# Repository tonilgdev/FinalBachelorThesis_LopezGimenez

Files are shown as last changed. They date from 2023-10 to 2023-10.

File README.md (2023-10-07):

# Antoni López Giménez's final bachelor's degree thesis repository

SEPTEMBER '23 UPDATE
> Currently, the repository is public and contains all the documents, code and hardware. The aim is to make it easily accessible.

ABSTRACT
> The aim of this project is to carry out a study of variations in human peripheral temperature as affected by stress, sleep and/or physical activity. To do this we have divided the project into two parts: the development of the measurement system and the assessment of this end. In order to be able to carry out the assessment correctly, we need to develop a system that can obtain the peripheral temperature of the subject to be studied and also know if it has been affected by physical activity. For this purpose we have developed a measurement system with a temperature sensor and an accelerometer as well as an RTC to be able to know at what instant of time the data have been collected. Finally, the assessment consists of the test subject taking the system with him/her for 2-3 days and returning it to download the data for analysis.

© 2021 Antoni López Giménez. All rights reserved.

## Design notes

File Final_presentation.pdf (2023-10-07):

Author: Antoni López

Advisor: Juan José Ramos

# Design of a system for ambulatory measurement of peripheral temperature

# Abstract

- The aim of this project is:
- Variations in human peripheral temperature as affected by stress, sleep and/or physical activity.
- Development of the measurement system.
- Peripheral temperature of the subject to be studied and its relation with physical activity.
- Measurement system with a temperature sensor and an
accelerometer.
- 2-3 subject study.

## Index

1. Introduction
a. Statement of purpose
b. Requirements and specifications
c. Methods and procedures
2. State of the art
a. Why peripheral temperature?
b. Specific components and I2C bus
c. Software tools
3. Project development
a. Hardware part
b. Software part
4. Results
5. Budget
6. Conclusions
a. Project conclusions
b. Own conclusions
c. Incidents
7. Future Development

# Introduction

## Statement of purpose

- Previous scientific studies about peripheral temperature
- Develop the measurement system
- Specific hardware

## Requirements

- User-friendly
- Similar to Smartwatch
- 2-3 autonomy days with data storage
- Continuous recording of Temperature and physical activity

## Specifications (I)

- Microcontroller
- RTC (Real Time Clock)
- EEPROM memory
- micro-USB connection
- USB charger
- LDO (Low Dropout
Regulators)
- Temperature sensors (2)
- Accelerometer
- Battery
- Reset button
- In Circuit Programing
interface
- Optional: three LEDS
(Green, Blue and Red)

Specifications (II) ● Arduino IDE ● Short time execution ● Auto-sleep mode ● Test mode → Print Data ● Menu with sections: ○ | STOP ○ | START ○ | SEND ○ | RESET ○ | READ

## Methods and procedures

- Previous work in the lab
- Adafruit Trinket M0
- Own PCB
■ USB charger
■ LDO
■ EEPROM memory
■ Temperature sensors
- No physical activity measurement
- Union of the two parts
- Code and components changes

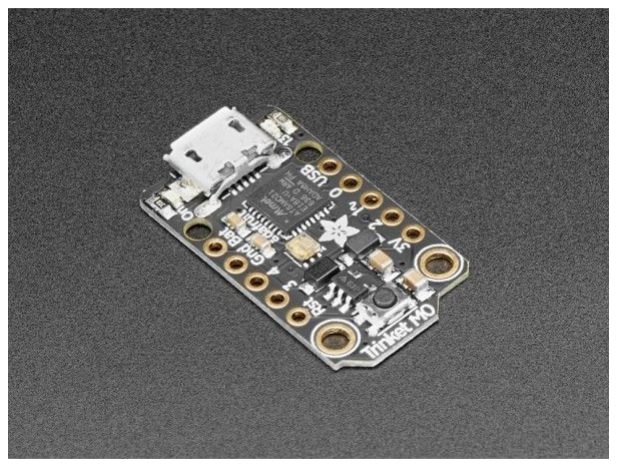
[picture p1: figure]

# State of the art

## Why peripheral temperature?

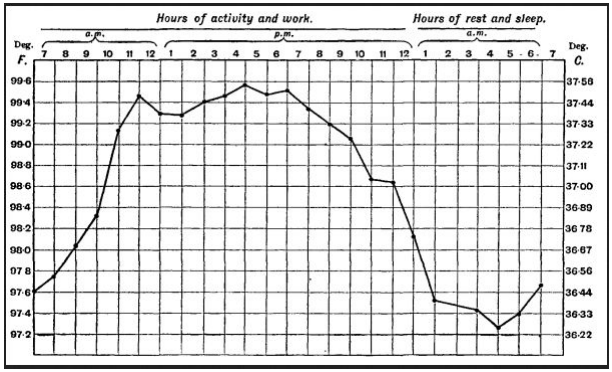
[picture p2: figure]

## Specific components and I2C bus

- Components compatible with I2C bus
- ¿Why I2C bus?
- ¿How works I2C bus?

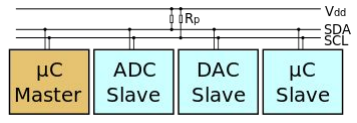
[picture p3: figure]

## Software tools

- KiCad EDA → PCB design
- Arduino IDE → Microcontroller programming
- Microchip Studio → Upload Arduino bootloader
- CoolTermWin → Terminal to store data
- Freedom Sensor Toolbox → Accelerometer Software
- Matlab → Convert Data
- Fusion 360 → Box design

# Project Development

## Hardware part (Block Diagram)

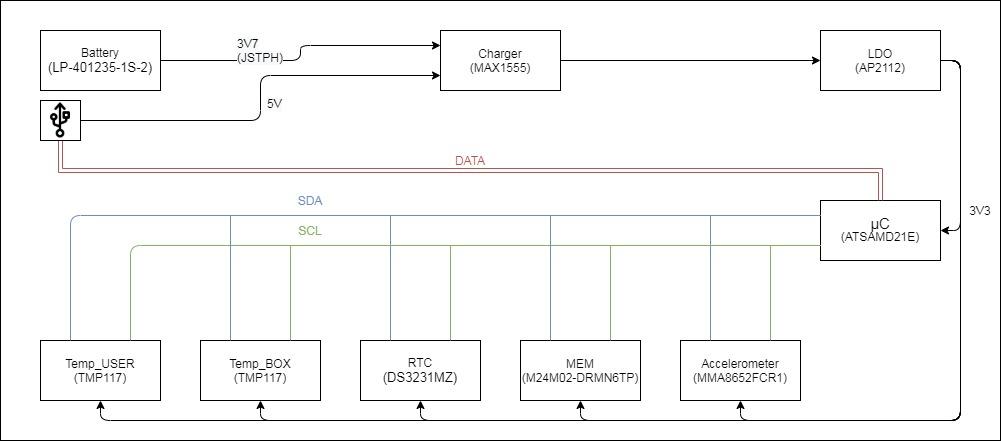
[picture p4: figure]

## Hardware part (Schematic)

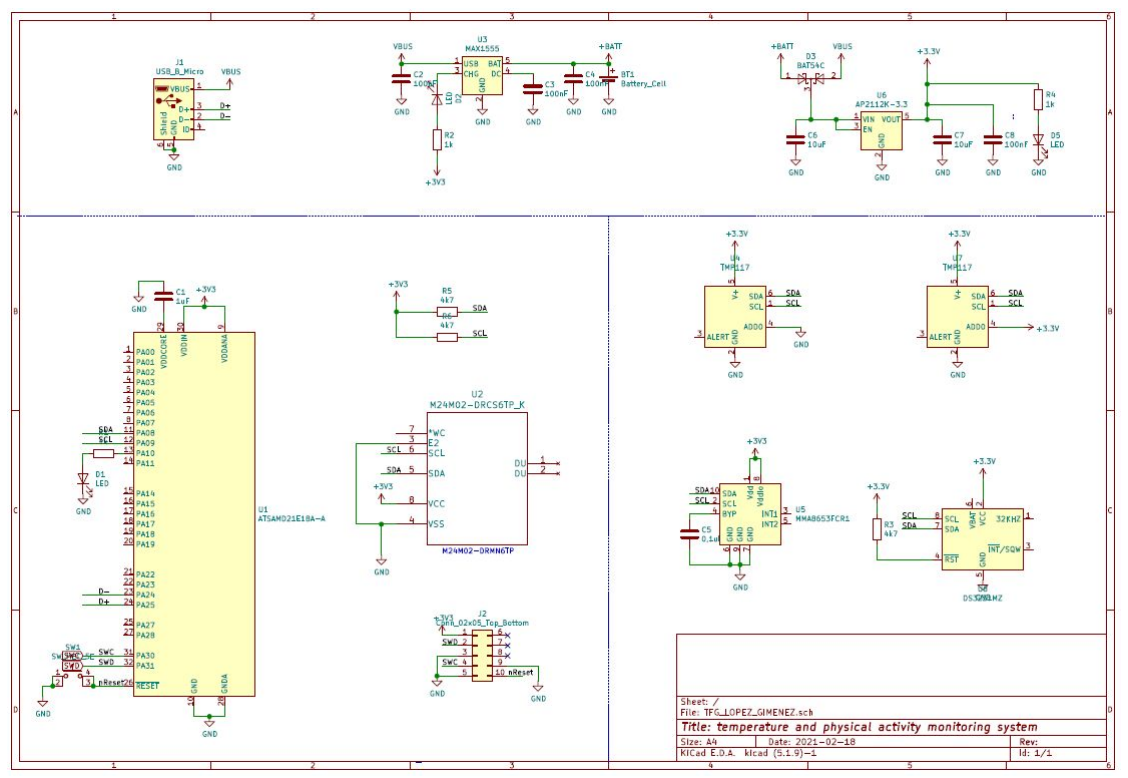
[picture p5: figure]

# Hardware Part

- Temperature:
- Accuracy: ±0.2°C (–10°C to +85°C)
- Resolution: 0.0078°C
- Sensor type: Diode temperature sensor?
- Physical activity → accelerometer:
- Type of sensor: capacitive micromachined accelerometer
- How it works? Integrated embedded functions + 3 capacitance transducers
- Saving information → EEPROM memory

## Hardware part (Prototype board)

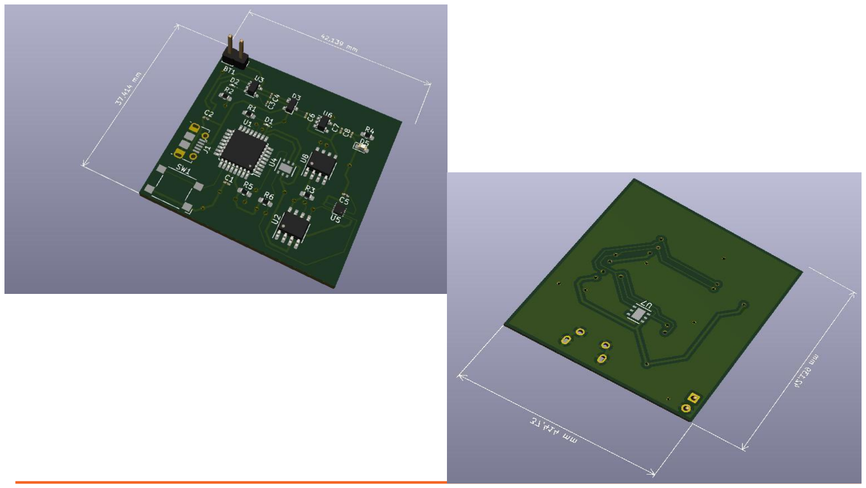
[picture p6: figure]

## Hardware part (Final board)

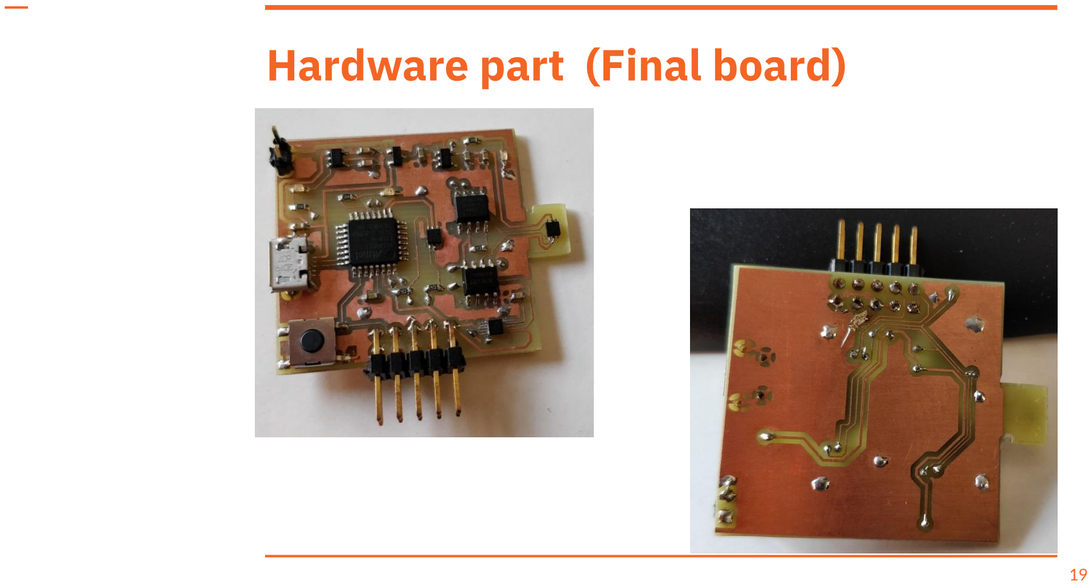
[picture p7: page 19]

## Software part

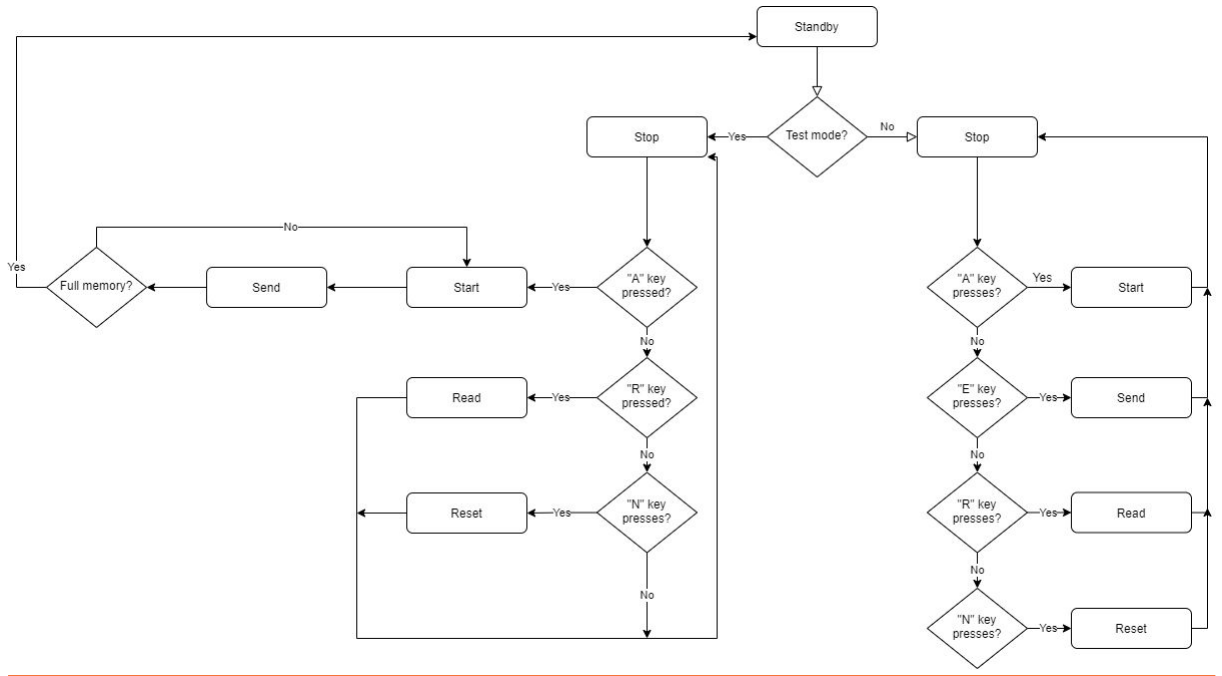
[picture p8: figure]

# Software Part

- Struct Data: ○ [Byte] day ○ [Byte] month ○ [Int] year ○ [Byte] hour ○ [Byte] min ○ [Byte] sec ○ [Float] int_temp ○ [Float] pat_temp ○ [Bool] phy_act

# Software Part

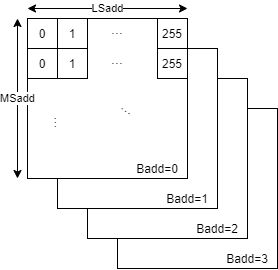
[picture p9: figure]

# Results

## Accelerometer communication

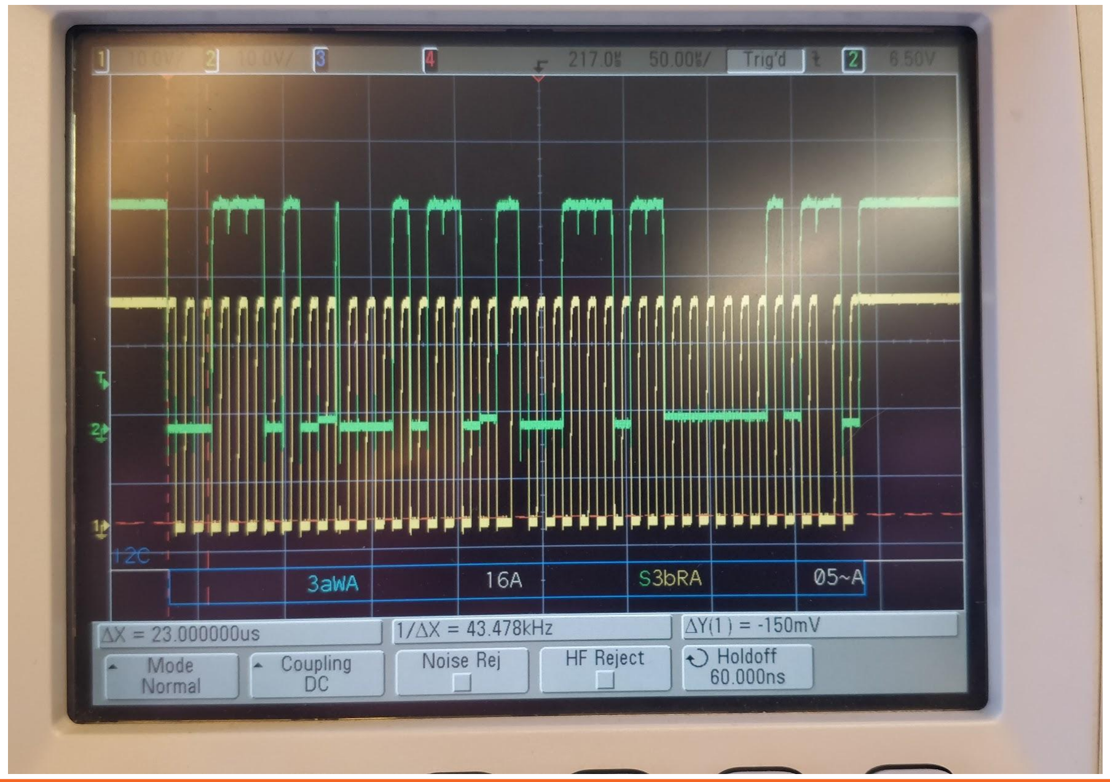
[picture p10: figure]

## Consumption

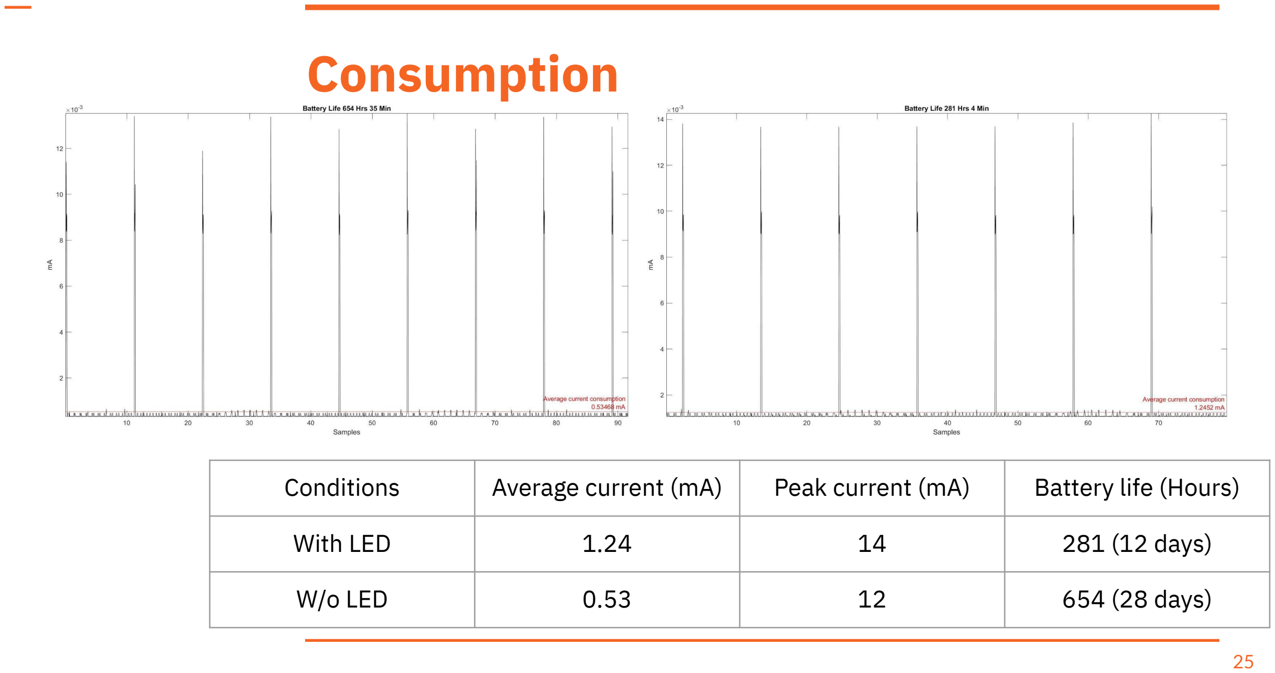
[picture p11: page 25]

Conditions | Average current (mA) | Peak current (mA) | Battery life (Hours)
With LED | 1.24 | 14 | 281 (12 days)
W/o LED | 0.53 | 12 | 654 (28 days)

## Charging mode

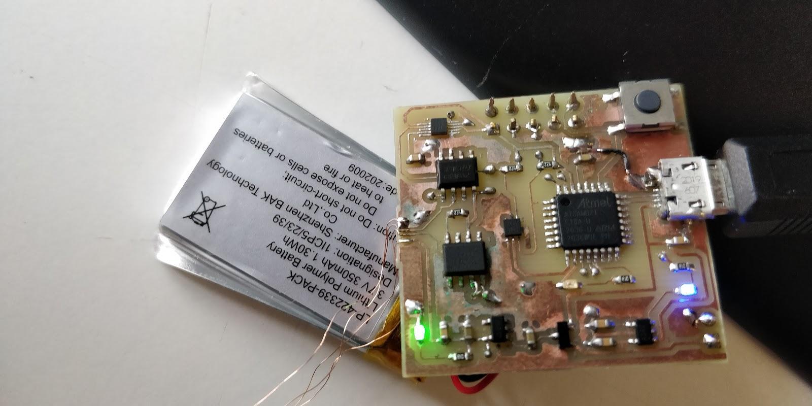
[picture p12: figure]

## Acquisition mode

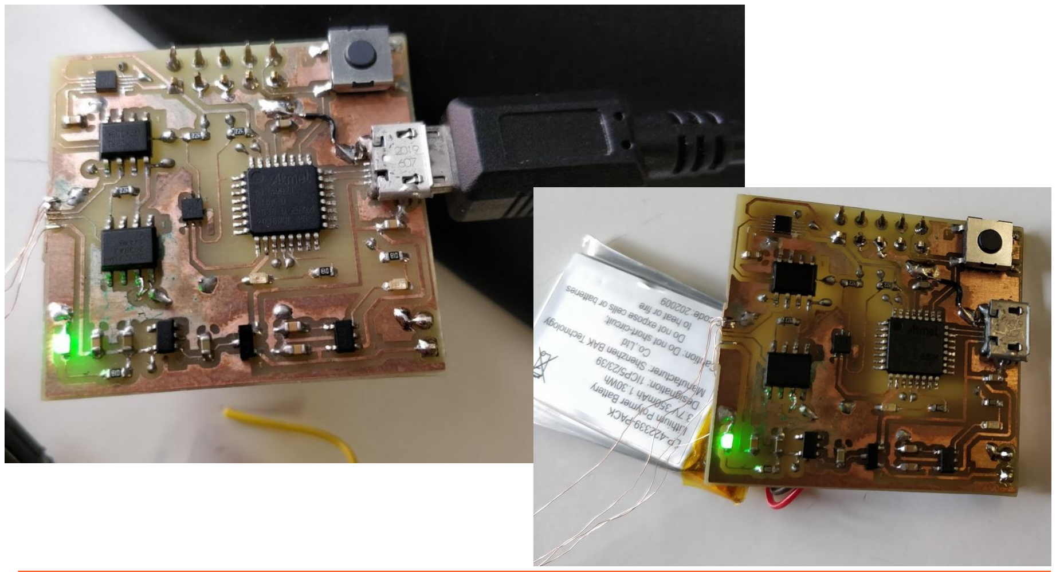
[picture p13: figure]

## Acquisition mode (I)

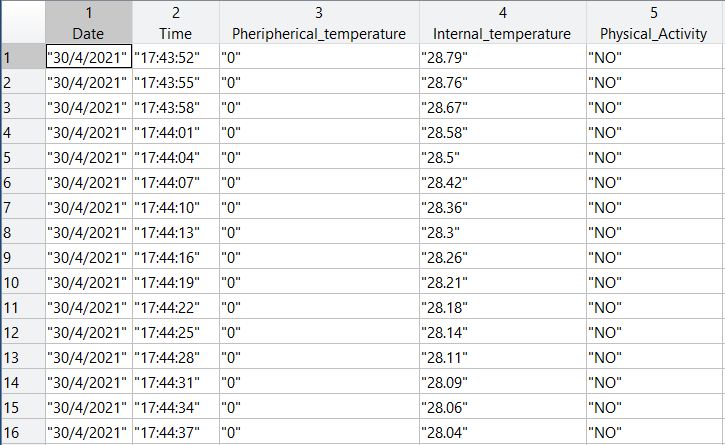
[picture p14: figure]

## Acquisition mode (II)

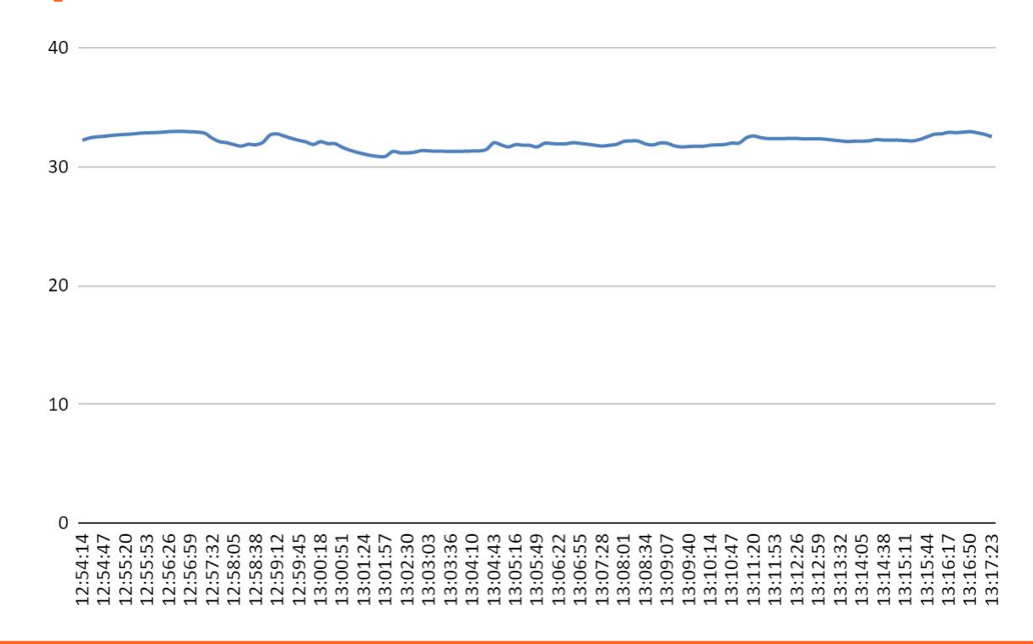
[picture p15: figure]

# Budget

# Components

# Budget

Component | Commercial Price (€) | Quantity | Subtotal(€)
ATSAMD21E18A-AU | 3.3 | 2 | 6.6
AP2112K-3.3TRG1 | 0.655 | 2 | 1.31
DS3231MZ+ | 6.24 | 2 | 12.48
TMP116AIDRVR | 4.1 | 3 | 12.3
M24M02-DRMN6TP | 2.93 | 2 | 5.86
MMA8652FCR1 | 1.96 | 2 | 3.92
MAX1555EZK+T | 1.61 | 2 | 3.22
B3FS-1000 | 0.18 | 2 | 0.36
MOLEX105017-000
1 | 0.724 | 2 | 1.45
BAT54C,215 | 0.144 | 2 | 0.288
YOBLP422339PACK | 19.96 | 2 | 39.92
| | TOTAL | 87.71

# Personal

# Budget

Workers | Salary/Hour (€) | Total Hours | Cost (without taxes)
Junior Engineer | 9 | 430 | 3870
Laboratory Technician | 35 | 20 | 700
| TOTAL | 5570

With that the total budget of the project is 4657,71€.

# Conclusions

## Project Conclusions

- Friendly and easily microcontroller IDE programming
- It needed extra time
- Delay in deadline
- PCB desgin
- SMD soldering
- Improvement in battery autonomy (12 days vs 2-3 theoretical days)
- Accelerometer soldering and programming problems

## Own conclusions

- Too optimistic
- My injury didn’t helps me
- Lack of experience
- A lot of learning and experience

## Incidents

- No time for scientific survey
- Find the correct box design
- Problems with Read and Write EEPROM memory
- Lack of experience in SMD components soldering
- Lack of guaranties with accelerometer soldering

# Future Development

# Improvements

- Components Packaging
changes
- Exercise algorithm
- LEDs remove
- Box changes

# Dedication

I want to dedicate this thesis to my mother because she helped and supported me every day during my bachelor’s degree and also for being mother and father at the same time. Without her advice and support, maybe I would not have finished my bachelor’s degree.

Thanks mum.

# Thanks for listening!

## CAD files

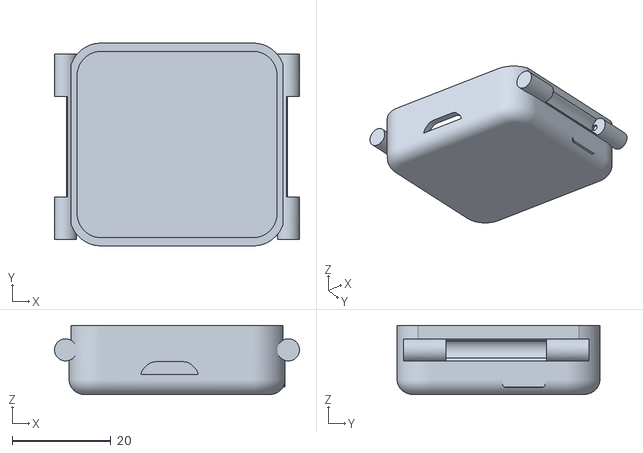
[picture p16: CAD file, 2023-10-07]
3D_Files/Caja_DEF_TONI_v4.stl
49.6 x 41.1 x 14.0

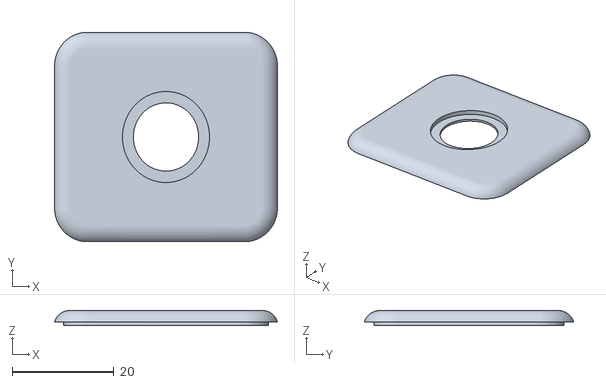
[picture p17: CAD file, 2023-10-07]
3D_Files/Tapa2_v4.stl
43.9 x 41.2 x 3.00

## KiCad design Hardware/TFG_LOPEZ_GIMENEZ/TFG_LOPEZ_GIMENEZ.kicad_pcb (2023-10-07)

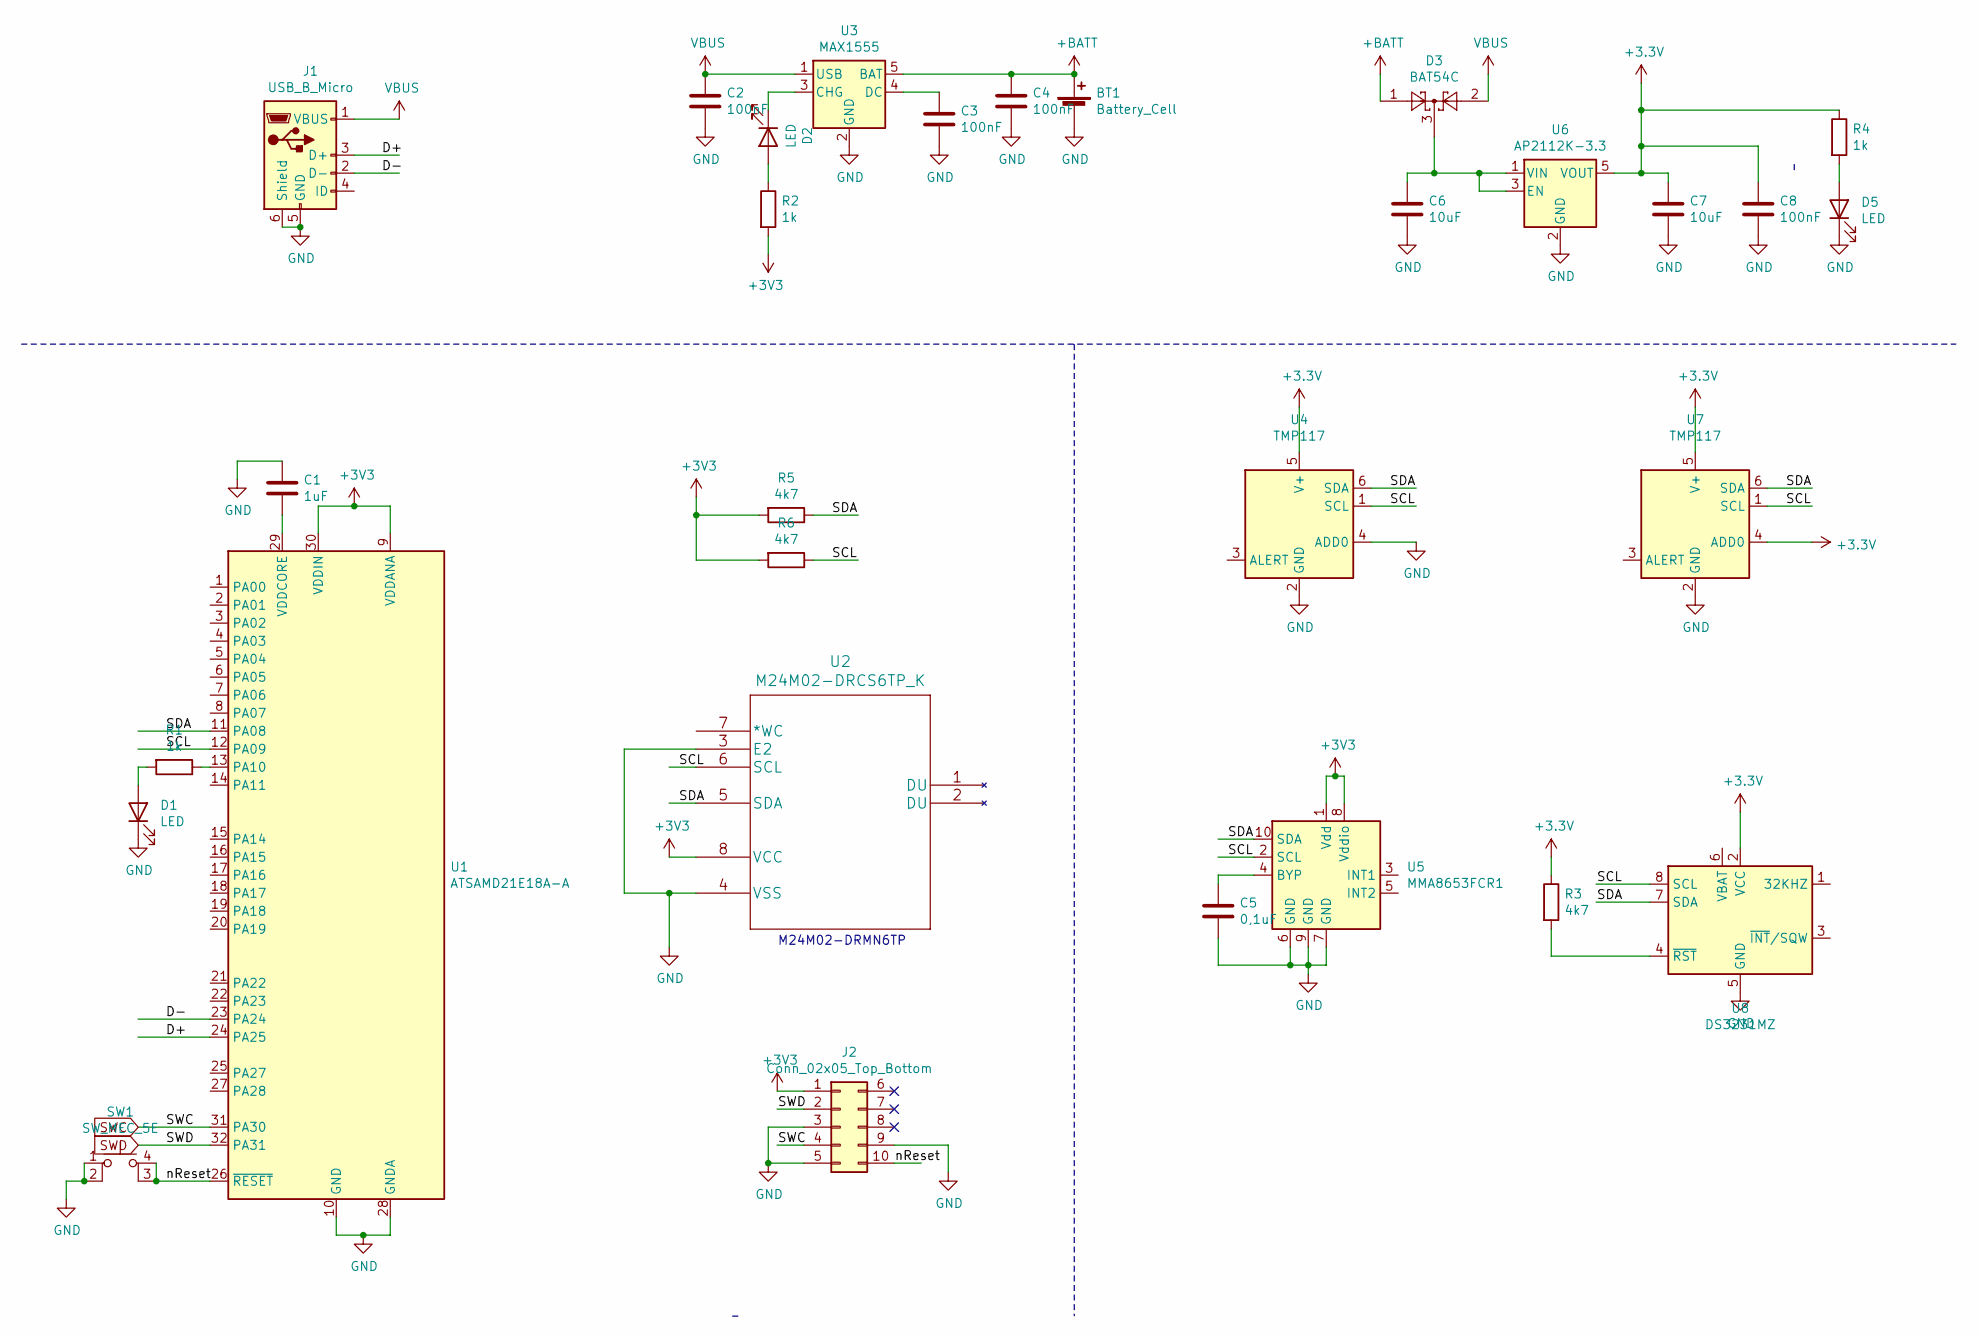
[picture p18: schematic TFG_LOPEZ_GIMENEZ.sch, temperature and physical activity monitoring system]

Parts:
BT1: Battery_Cell; PinHeader_1x02_P2.54mm_Vertical
C1: 1uF; C_0603_1608Metric_Pad1.08x0.95mm_HandSolder
C2, C3, C4, C8: 100nF; C_0603_1608Metric_Pad1.08x0.95mm_HandSolder
C5: 0,1uF; C_0603_1608Metric_Pad1.08x0.95mm_HandSolder
C6, C7: 10uF; C_0603_1608Metric_Pad1.08x0.95mm_HandSolder
D1, D2, D5: LED; LED_0603_1608Metric_Pad1.05x0.95mm_HandSolder
D3: BAT54C; SOT-23
J1: USB_B_Micro; USB_Micro-B_Molex-105017-0001
J2: Conn_02x05_Top_Bottom; PinHeader_2x05_P2.54mm_Vertical
R1, R2, R4: 1k; R_0603_1608Metric_Pad0.98x0.95mm_HandSolder
R3, R5, R6: 4k7; R_0603_1608Metric_Pad0.98x0.95mm_HandSolder
SW1: SW_MEC_5E; SW_SPST_Omron_B3FS-100xP
U1: ATSAMD21E18A-A; TQFP-32_7x7mm_P0.8mm
U2: M24M02-DRCS6TP_K; SOIC-8_3.9x4.9mm_P1.27mm
U3: MAX1555; SOT-23-5
U4, U7: TMP117; TMP116AIDRVR
U5: MMA8653FCR1; DFN-10_2x2mm_P0.4mm
U6: AP2112K-3.3; SOT-23-5
U8: DS3231MZ; SOIC-8_3.9x4.9mm_P1.27mm

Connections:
+BATT: BT1.1 (+), C4.1, D3.1, U3.5 (BAT)
/D+: J1.3 (D+), U1.24 (PA25)
/D-: J1.2 (D-), U1.23 (PA24)
/SCL: R6.1, U1.12 (PA09), U2.6 (SCL), U4.1 (SCL), U5.2 (SCL), U7.1 (SCL), U8.8 (SCL)
/SDA: R5.1, U1.11 (PA08), U2.5 (SDA), U4.6 (SDA), U5.10 (SDA), U7.6 (SDA), U8.7 (SDA)
/nReset: J2.10, SW1.3 (K), SW1.4 (A), U1.26 (~RESET)
GND: BT1.2 (-), C1.1, C2.2, C3.2, C4.2, C5.2, C6.2, C7.2, C8.2, D1.1 (K), D5.1 (K), J1.5 (GND), J1.6 (Shield), J2.3, J2.5, J2.9, SW1.1, SW1.2, U1.10 (GND), U1.28 (GND), U2.3 (E2), U2.4 (VSS), U3.2 (GND), U4.2 (GND), U4.4 (ADD0), U5.6 (GND), U5.7 (GND), U5.9 (GND), U6.2 (GND), U7.2 (GND), U8.5 (GND)
unnamed: C1.2, U1.29 (VDDCORE)
unnamed: C3.1, U3.4 (DC)
unnamed: C5.1, U5.4 (BYP)
unnamed: C6.1, D3.3, U6.1 (VIN), U6.3 (EN)
unnamed: D1.2 (A), R1.2
unnamed: D2.1 (K), U3.3 (CHG)
unnamed: D2.2 (A), R2.1
unnamed: D5.2 (A), R4.2
unnamed: R1.1, U1.13 (PA10)
unnamed: R3.2, U8.4 (~RST)
SWC: J2.4, U1.31 (PA30)
SWD: J2.2, U1.32 (PA31)
VBUS: C2.1, D3.2, J1.1 (VBUS), U3.1 (USB)

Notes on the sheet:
M24M02-DRMN6TP

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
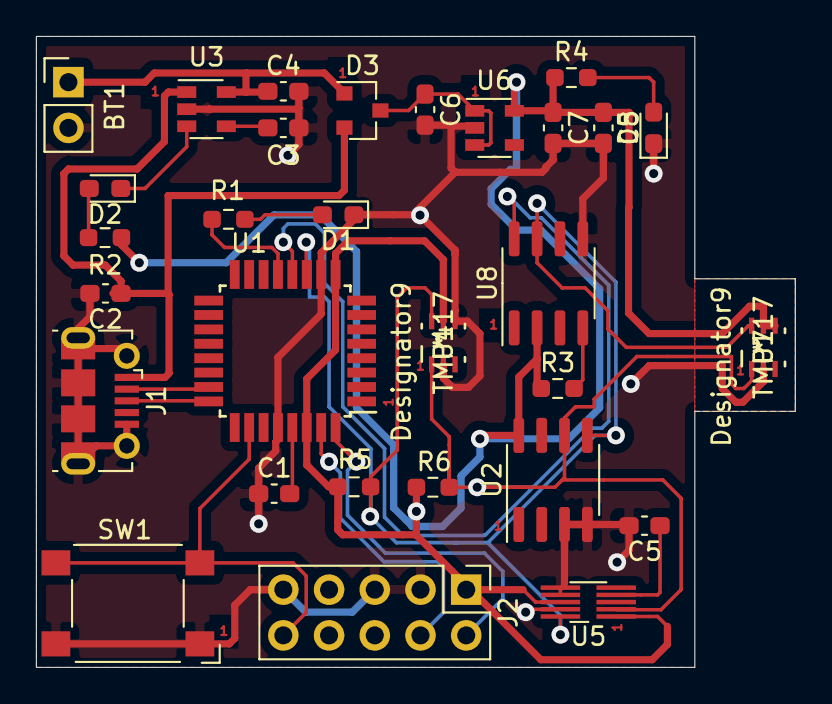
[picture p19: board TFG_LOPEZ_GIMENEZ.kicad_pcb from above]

Board: 2 copper layers, 42.2 x 35.1 mm, 30 parts (0 on the bottom side), 21 nets.

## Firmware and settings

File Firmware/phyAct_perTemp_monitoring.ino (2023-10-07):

//Author: Antoni López Giménez
//University: UPC (2021)

//Useful Libraries
#include "ArduinoLowPower.h"
#include <Wire.h> //Library to use the I2C 
#include "RTClib.h" //Library to use DS3231
#include <RTCZero.h> // Library to use internal RTC 
#include <Adafruit_SleepyDog.h>//Library to use intern Watchdog timer 
#include "ClosedCube_TMP116.h"
#include "mma8652.h" //Library to use the accelerometre (MMA8652FCR1)

//States of the program and commands to send
#define STOP 0 //S
#define START 1 //A
#define SEND 2 //E
#define RESET 3 //N
#define READ 4 //R
 

//Microcontroller pin assigments
const int LED = 13; //Help you to know if the Arduino bootloader is correctly programmed

//Useful variables
byte State = 0; //Solve the actual state

//Temperature Sensor definitions
uint8_t ADDR_GND =  0x48;   // Skin sensor adress
uint8_t ADDR_VCC =  0x49;   // Internal sensor adress
//TMP117 SKIN_tmp(ADDR_GND); //Adress assigment
//TMP117 INT_tmp(ADDR_VCC); // Adress assigment
ClosedCube::Sensor::TMP116 SKIN_tmp;
ClosedCube::Sensor::TMP116 INT_tmp;

//Internal RTC definitions
RTCZero intRTC;
boolean TEST = false; //Variable for controling acquisition or send data (in acquisition mode goes to sleep TEST=0)
// Set how often alarm goes off here
const byte alarmSeconds = 10;
const byte alarmMinutes = 0;
const byte alarmHours = 0;
volatile bool alarmFlag = true; // Start awake

//External RTC (DS3231) definitions (0x68 default device address)
RTC_DS3231 extRTC;
const char daysOfTheWeek [7][12]={"Sunday","Monday","Tuesday","Wednesday", "Thursday", "Friday", "Saturday"};

//Accelerometer definitions (0x1D default device address)
#define ACC_INT 11
#define actCount 0x80
#define accTHS 0x40
MMA8652 accel= MMA8652(ACC_INT);

//EEPROM MEMORY 
//EEPROM has I2C addresses 0x50, 0x51, 0x52 and 0x53 (0x50 | 0x00, 0x50 | 0x01,0x50 | 0x02 and 0x50 | 0x03)
#define EEPROM_DATA_ADD 0x50 // Address of the first 1024 page M24M02DRC EEPROM data buffer, 2048 bits (256 8-bit bytes) per page
#define EEPROM_IDPAGE_ADD 0x58 // Address of the single M24M02DRC lockable ID page of the EEPROM
#define length_Fblock 12 //Length of first block of data (16 bytes)[0..15]
#define length_Sblock 8 //Length of second blocks of data (12 bytes) [0..11]
#define L_MSmax 256 //Maximum of pages per block and maximum data per page
#define maxBlocks 31 //Maximum number of blocks can be sended per page
#define Bmax 3
uint8_t Badd=0, MSadd=0, LSadd=0; //Badd=Block address (0-3) ; MSadd=MSB(page 0-255) ; LSadd=LSB(0-255)
bool EEPROM_empty = true;
int currentBlocks, sendedBlocks=31744; //(==31744 if you want read memory)

//Obtained data
struct data{ //Struct with all the variables that we will need
  byte day;
  byte month;
  int year;
  byte hour;
  byte min;
  byte sec;
  float int_temp;
  float pat_temp;
  bool phy_act;
};
typedef struct data Data; 
Data ReadData; //data to print
Data ObtData; //Obtanined data to storage
uint8_t clearData[256]; //Variable to reset the EEPROM memory
uint8_t receiveData[L_MSmax]; //Variable to receive byte to byte from EEPROM memory

//Useful variables
byte prevHour;
byte prevMin;
int tt1=0, tt2=0;
int countdownMS;


void setup() {
 
  Wire.begin();
  Serial.begin(115200); //opens serial port, sets data rate to 115200 bps
  while (!Serial) ;
  Serial.println("Setup");
  pinMode(LED,OUTPUT);
  
  //Temperature sensors initialize (ver funciones)
  SKIN_tmp.address(ADDR_GND);
  INT_tmp.address(ADDR_VCC);
    
  //External RTC initialize
  if (! extRTC.begin()) {
    Serial.println("Couldn't find RTC");
    Serial.flush();
    abort();
  }
  if (extRTC.lostPower()) {
    Serial.println("RTC lost power, let's set the time!");
    // When time needs to be set on a new device, or after a power loss, the
    // following line sets the RTC to the date & time this sketch was compiled
    extRTC.adjust(DateTime(F(__DATE__), F(__TIME__)));
    // This line sets the RTC with an explicit date & time, for example to set
    // January 21, 2014 at 3am you would call:
    // rtc.adjust(DateTime(2014, 1, 21, 3, 0, 0));
  }else{
    extRTC.adjust(DateTime(F(__DATE__), F(__TIME__)));
  }

  //Internal RTC initialize if TEST=FALSE
  if(TEST==false){
    intRTC.begin(); // Set up clocks and such
    resetAlarm();  // Set alarm
    intRTC.attachInterrupt(alarmMatch); // Set up a handler for the alarm
    digitalWrite(LED,LOW);
    Serial.println("DORMIREMOS");
    delay(1000);
    //countdownMS=Watchdog.enable(alarmSeconds*1000);
    LowPower.attachInterruptWakeup(RTC_ALARM_WAKEUP, onWakeup, CHANGE);
    State=STOP;
  }else{
    digitalWrite(LED,HIGH);
  }
  
  
  //Acelerometre initialize 0x1D device adress
  //cambiar init  a 8g
  accel.init();
  delay(1);
  accel.write(F_SETUP_REG,F_MODE_FILL); //Allow mode 1 of FIFO (Fill) if we need a circular fifo you change the second parameter to F_MODE_CIRCULAR for more details read the information in github repository
  //accel.write(OFF_X_REG, X_OFFSET_X); //Congifuration of X-axis offset 
  //accel.write(OFF_Y_REG, Y_OFFSET_y); //Congifuration of Y-axis offset 
  //accel.write(OFF_Z_REG, Z_OFFSET_Z); //Congifuration of Z-axisoffset 
  // Enable Free-Fall detection interrupt
  accel.enableFreeFallInt(accTHS); //the hexadecimal parameter is the sensibility FF_MT_THS
  delay(1);
  
  
}

void loop() {

 byte command;

 switch (State){
  
  case STOP:{
    
       
    if(Serial.available()>0){
    
      command=Serial.read();
      switch (command){
        case 'S':{
          State= STOP;
          Serial.println("STOPPING");
          delay(100);
          //Watchdog.disable();
          break;
        }
        case 'A':{
          State=START;
          Serial.println("CHANGING TO ACQUISITION MODE");
          delay(100);
          //countdownMS=Watchdog.enable(alarmSeconds*1000);
          break;          
        }
        case 'E':{
          
          State=SEND; 
          break;
        }
        case 'N':{
          Serial.println("RESETTING THE MEMORY");
          State=RESET; 
          break;
        }
        case 'R':{          
          State=READ;
          break;          
        }
      }
      // Plot menu
      Serial.println("  ");
      Serial.println("  ");
      Serial.println("S Stop Acquisition");
      Serial.println("A Start Acquisition, goes to sleep");
      Serial.println("E Send acquired data");
      Serial.println("N Reset memory (acquired data)");
      Serial.println("R Read data acquired");
      Serial.println("  ");
      Serial.println("  ");
    }
    break;
  }//case:STOP

  case START:{
   
  if(Badd>=4){ //Exceed the number of blocks
    EEPROM_empty=false;
    Serial.println("Full memory, STOP acquisition");
    Serial.print("Blocks sended: ");
    Serial.println(sendedBlocks);
    State=STOP;
    Watchdog.disable();
    break;
  }

  if (TEST==false){
    
    //AQUI HAY QUE DORMIRLO
    Serial.println("Zzzzz..."); 
    digitalWrite(LED, LOW);   
    if(alarmFlag == true) alarmFlag = false; //Clear flag
    resetAlarm();
    //intRTC.standbyMode();
    LowPower.sleep(alarmSeconds*1000);
    USBDevice.attach(); 
    //Watchdog.reset();    
   
    Serial.println("Hello World");   
    readSensors();
    State=SEND;
    command=Serial.read();
    if(command=='S'){
      State=STOP;
      break;
    }
    
  }else{

    //AQUI NO DUERME   
    readMemory();
    //readSensors();
    testReadSensors();   
    State=SEND;
    command=Serial.read();
    if(command=='S'){
      State=STOP;
      break;
    }
    
  }
    
  break;
  
  }//case:START
  
  case SEND:{
    
    if(LSadd==0){
      
      M24M02DRCwriteBytes(EEPROM_DATA_ADD | Badd, MSadd, LSadd, true, ObtData); //OWN function to send data
      delay(10);// It takes a maximum of 10 ms for a read or write operation; the EEPROM won't respond until the operation is done
      LSadd=LSadd+length_Fblock; //increasing the number of bytes written to the page
      currentBlocks++;
      sendedBlocks++;
           
    }else{
      
      M24M02DRCwriteBytes(EEPROM_DATA_ADD | Badd, MSadd, LSadd, false, ObtData); 
      delay(10);
      LSadd= LSadd+length_Sblock;
      currentBlocks++;
      sendedBlocks++;
      if(currentBlocks == maxBlocks){
        /*Serial.println(sendedBlocks);
        Serial.println(Badd);
        Serial.println(MSadd);
        Serial.println(LSadd);*/
        LSadd=0;
        MSadd++;
        currentBlocks=0; 
               
        if(MSadd == 0){
          Badd++;
          Serial.println("BLOQUE ACTUALIZADO");
          delay(500);           
        }
      }
      /*Serial.println(sendedBlocks);
      Serial.println(Badd);
      Serial.println(MSadd);
      Serial.println(LSadd);*/
    }

    if(TEST==false){
      State=START;
      break;
    }else{
      State=STOP;
      break;
    }
    
  }//case:SEND
  
  case RESET:{

    //RESET EEPROM MEMORY
    for(uint8_t B=0; B < 4; B++){ //fixing block
      for(uint8_t M=0; M < (L_MSmax-1); M++){ //fixing MSB
        M24M02DRCclear(EEPROM_DATA_ADD | B, M, 0,clearData);
        delay(10);
      }
      M24M02DRCclear(EEPROM_DATA_ADD | B, 255, 0,clearData);
      delay(10);
    }
    EEPROM_empty=true;
    
    //RESET ACCELEROMETRE

    State=STOP;
    break;
  }//case:RESET
  
  case READ:{
  int s=0;
  uint8_t B=0;
  while(B<=Bmax){    
      for(uint8_t M=0; M < (L_MSmax-1) ; M++){    //&& s<=sendedBlocks  
        M24M02DRCreadBytes(EEPROM_DATA_ADD | B, M, 0);
        delay(10);
        s+=31;          
        printData();
       }
       M24M02DRCreadBytes(EEPROM_DATA_ADD | B, 255, 0);
      delay(10);
      s+=31;          
      printData();
      B++;
    }
    State=STOP;
    break;
  }//case:READ
   
 }//switch
}//loop


/////////////////////
//USEFUL FUNCTIONS//
///////////////////

//Reset Internal RTC ALARM
void resetAlarm(void){

  //Obtain current time
  //DateTime now = current_Time();
  
  //Set current Time and Date in the internal RTC
  //intRTC.setTime(now.hour(),now.minute(),now.second());
  //intRTC.setDate(now.year(),now.minute(),now.second());
  intRTC.setTime(00,00,00);
  intRTC.setDate(1,1,1);

  //Set alarm time select previously
  intRTC.setAlarmTime(alarmHours, alarmMinutes, alarmSeconds);
  //intRTC.setAlarmTime(now.hour()+alarmHours, now.minute()+alarmMinutes, now.second()+alarmSeconds);
  intRTC.enableAlarm(intRTC.MATCH_HHMMSS);
  
}

void alarmMatch(){ //REVISAR
  digitalWrite(LED, HIGH);
  alarmFlag = true; // Set flag
}

//Get current Time
DateTime current_Time(){
  return extRTC.now();
}

//Send bytes to EEPROM it's an adaptation of the function in github repository (it's thinking to have two different devices in the same design)
void M24M02DRCwriteBytes(uint8_t device_address, uint8_t page_address, uint8_t data_address, bool first, Data dest){
  
  int int_int =(int)(dest.int_temp*100);
  int int_skin=(int)(dest.pat_temp*100);
  //int int_int =(int)(dest.int_temp);
  //int int_skin=(int)(dest.pat_temp);
  
  if(first == true) {
    
    Wire.beginTransmission(device_address); // Initialize the Tx buffer
    Wire.write(page_address); // Put slave register address in Tx buffer
    Wire.write(data_address); // Put slave register address in Tx buffer
    Wire.write(dest.day);
    Wire.write(dest.month);
    Wire.write(dest.year >> 8);
    Wire.write(dest.year);
    Wire.write(dest.hour);
    Wire.write(dest.min);
    Wire.write(dest.sec);
    Wire.write(int_int >> 8);  //Sensor returns a float which we multiply*100 and we do a cast to int to be able to send via I2C
    Wire.write(int_int);
    Wire.write(int_skin >> 8);
    Wire.write(int_skin);
    Wire.write(dest.phy_act);        
    Wire.endTransmission(); // Send the Tx buffer
    
  } else{
    
    Wire.beginTransmission(device_address); // Initialize the Tx buffer
    Wire.write(page_address); // Put slave register address in Tx buffer
    Wire.write(data_address); // Put slave register address in Tx buffer
    Wire.write(dest.hour);
    Wire.write(dest.min);
    Wire.write(dest.sec);
    Wire.write(int_int >> 8);  
    Wire.write(int_int);
    Wire.write(int_skin >> 8);
    Wire.write(int_skin);
    Wire.write(dest.phy_act);     
    Wire.endTransmission(); // Send the Tx buffer
    //Serial.println(dest.hour);
  }
  
}

//Clear the EEPROM memory fully (own function, it's an adaptation of the writing function
void M24M02DRCclear(uint8_t device_address, uint8_t page_address, uint8_t data_address, uint8_t *dest){
    
    Wire.beginTransmission(device_address); // Initialize the Tx buffer
    Wire.write(page_address); // Put slave register address in Tx buffer
    Wire.write(data_address); // Put slave register address in Tx buffer
    
    for(uint16_t i=0; i < (L_MSmax-1) ; i++) {
      Wire.write(dest[i]); // Put data in Tx buffer
    }      
    Wire.endTransmission(); // Send the Tx buffer
}


//Read bytes from EEPROM it's and adaptation of the function in github repository (it's thinking to have two different devices in the same design)
void M24M02DRCreadBytes(uint8_t device_address, uint8_t page_address, uint8_t data_address){

     
  Wire.beginTransmission(device_address); // Initialize the Tx buffer
  Wire.write(page_address); // Put slave register address in Tx buffer
  Wire.write(data_address); // Put slave register address in Tx buffer
  Wire.endTransmission(false); // Send the Tx buffer, but send a restart to keep connection alive
  Wire.requestFrom(device_address,(L_MSmax-4)); // Read bytes from slave register address
  uint8_t i = 0;
  while(Wire.available()){
    receiveData[i] = Wire.read();
    //Serial.println(receiveData[i]);
    i++;
  }    
}

//Function to read all the Sensors
void readSensors(){
  
   //Read RTC
    DateTime fecha = current_Time();
    ObtData.day=fecha.day();
    ObtData.month=fecha.month();
    ObtData.year=fecha.year();
    ObtData.hour=fecha.hour();
    ObtData.min=fecha.minute();
    ObtData.sec=fecha.second();

    //Read Temperature
    ObtData.int_temp=INT_tmp.readTemperature();
    ObtData.pat_temp=SKIN_tmp.readTemperature();

    //Read Accelerometre
    //-------FORMA 1------
    if(accel.read(FF_MT_SRC_REG)>= 0x80){
      ObtData.phy_act=true;
      accel.read(FF_MT_SRC_REG);
    }else{
      ObtData.phy_act=false;
    } 
}

//Function to check the sensors
void testReadSensors(){
  
    //LEER TEMPERATURAS 
    Serial.print("Temperatura piel: ");
    Serial.print(ObtData.pat_temp);
    Serial.println("ºC");
    delay(100);
  
    Serial.print("Temperatura interna: ");
    Serial.print(ObtData.int_temp);
    Serial.println("ºC");
    delay(100);
    
    //LEER ACELEROMETRO
     //Read Accelerometre
    //-------FORMA 1------
    if(accel.read(FF_MT_SRC_REG)>= 0x80){
      ObtData.phy_act=true;
      Serial.println("EJERCICIO");      
    }else{
      ObtData.phy_act=false;
      Serial.println("ESPABILA");
    } 
    
    //LEER RTC EXTERNO
    //Leer fecha
    Serial.print("Fecha: ");
    Serial.print(ObtData.day,DEC);
    Serial.print("/");
    Serial.print(ObtData.month,DEC);
    Serial.print("/");
    Serial.print(ObtData.year,DEC);
    Serial.print(" at ");
    Serial.print(ObtData.hour,DEC);
    Serial.print(":");
    Serial.print(ObtData.min,DEC);
    Serial.print(":");
    Serial.println(ObtData.sec,DEC);
    delay(100);
}

//Fucntion to printData in EEPROM memory
void printData(){
  uint8_t c = 0;
  while(c<(L_MSmax-4)){
    Serial.print(receiveData[c],DEC);
    Serial.print(" ");
    c++;
  }
  Serial.println("");
}
    


void readMemory(){
  
   //Read RTC
    DateTime fecha = current_Time();
    ObtData.day=fecha.day();
    ObtData.month=fecha.month();
    ObtData.year=fecha.year();
    ObtData.hour=fecha.hour();
    ObtData.min=fecha.minute();
    ObtData.sec=fecha.second();

    //Read Temperature
    ObtData.int_temp=INT_tmp.readTemperature();
    ObtData.pat_temp=SKIN_tmp.readTemperature();

    //Read Accelerometre
    ObtData.phy_act=0;
    
    
}
void onWakeup() {
  
  digitalWrite(LED, HIGH);
}

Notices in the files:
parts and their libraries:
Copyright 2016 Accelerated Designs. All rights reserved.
